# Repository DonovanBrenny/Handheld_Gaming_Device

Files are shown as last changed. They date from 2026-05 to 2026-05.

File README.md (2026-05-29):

# Handheld Gaming Device

A PIC24FJ64GA002 handheld game console with a 128x128 OLED, dual analog
joysticks, and four built-in games. Firmware in C, hardware in KiCad.

## Games

- **Pong** - two-player, first to 5
- **Ackanoid** - brick breaker, 3 levels, 3 lives
- **Maze** - 2.5D raycaster on a randomly generated maze
- **Dinosaur Runner** - endless side-scroller, jump with the blue button

## Controls

- **Joysticks** - menu navigation and in-game movement
- **Blue button** - select / jump
- **Red button** - back
- **Joystick click + Red (held)** - exit a game to the main menu

## Build

MPLAB X IDE + XC16 compiler. Open the `.X` folder as a project, build, and
flash with a PICkit (or equivalent) via the ICSP header.

## Hardware

KiCad schematic and PCB live in `hardware/`. Built around a PIC24FJ64GA002
(28-pin DIP), an SH1107-class 128x128 OLED on SPI1, two analog joysticks,
two pushbuttons, and an NPN-driven piezo speaker. Pin assignments are in
[`Setup.c`](Setup.c).

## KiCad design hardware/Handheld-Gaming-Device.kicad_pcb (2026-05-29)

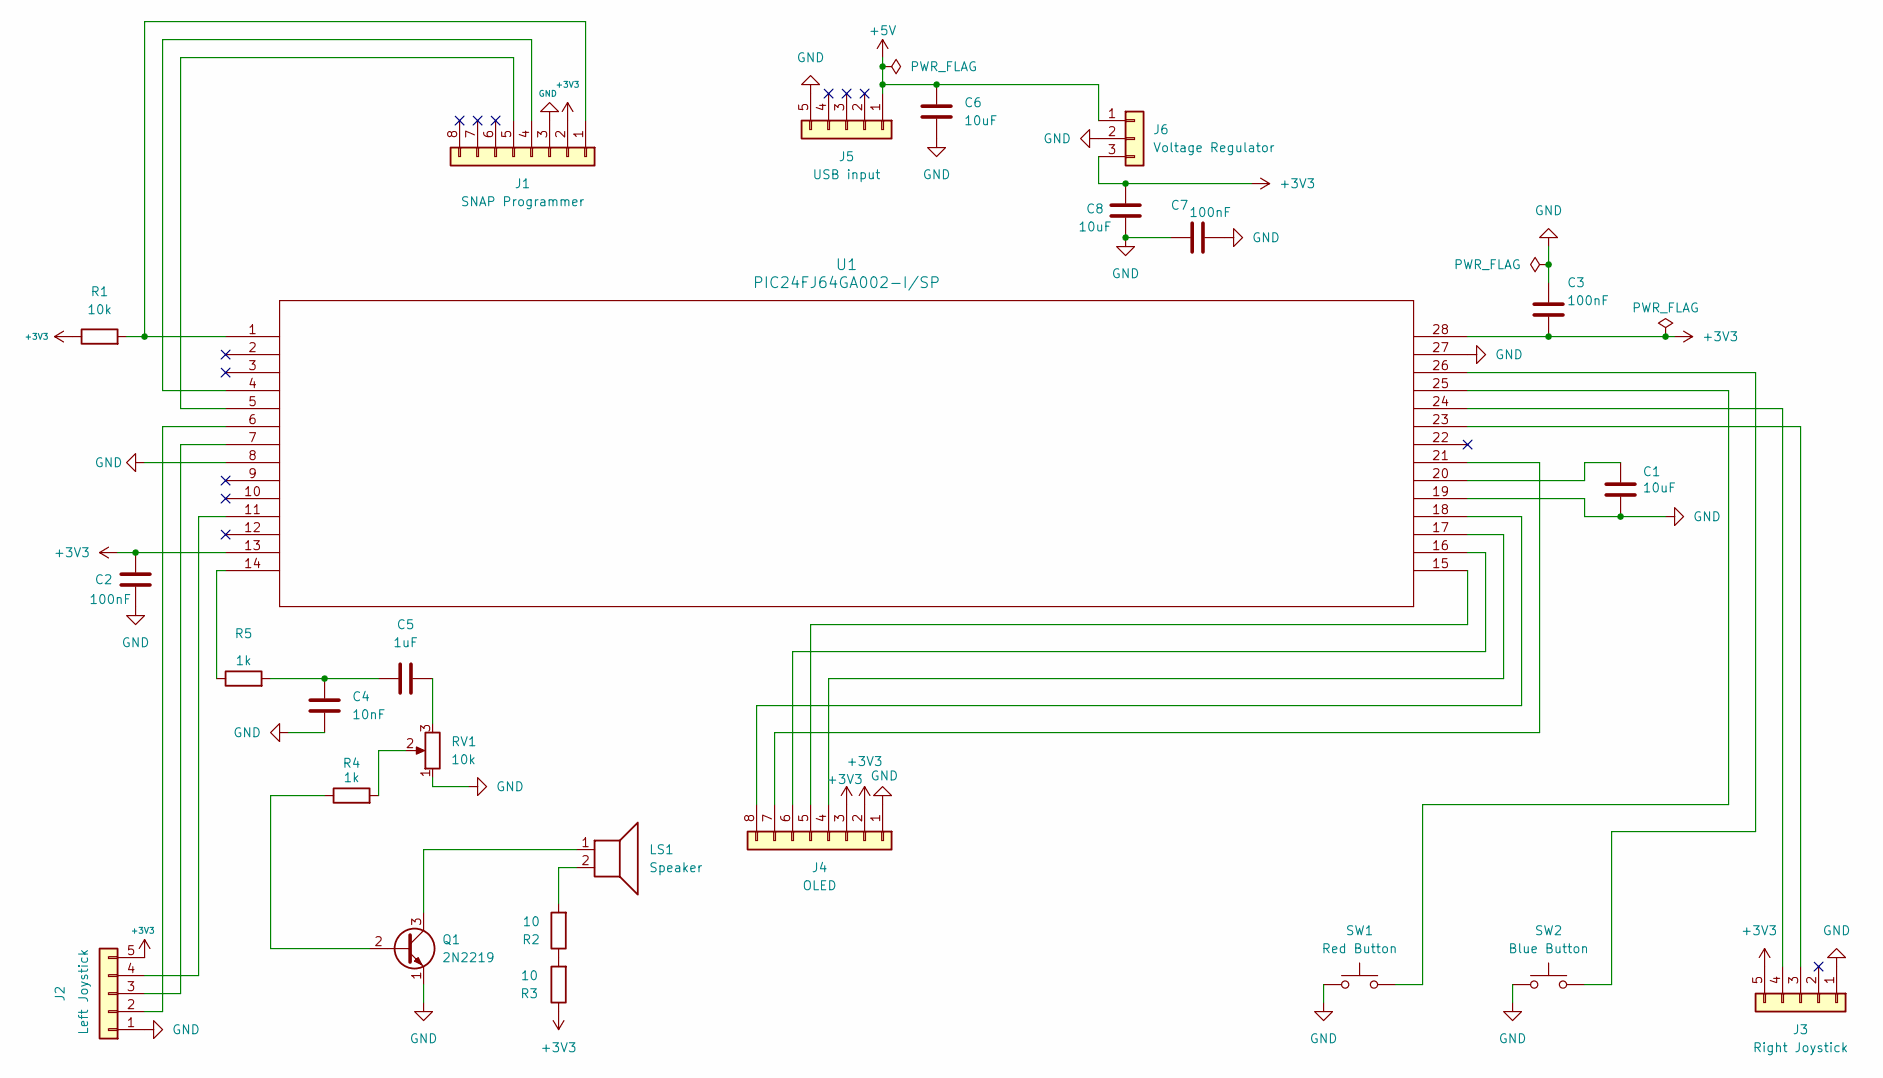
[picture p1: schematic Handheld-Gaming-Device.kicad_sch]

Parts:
C1, C6, C8: 10uF; C_Disc_D5.0mm_W2.5mm_P5.00mm
C2, C3, C7: 100nF; C_Disc_D5.0mm_W2.5mm_P5.00mm
C4: 10nF; C_Disc_D5.0mm_W2.5mm_P5.00mm
C5: 1uF; C_Disc_D5.0mm_W2.5mm_P5.00mm
J1: SNAP Programmer; PinSocket_1x08_P2.54mm_Vertical
J2: Left Joystick; PinSocket_1x05_P2.54mm_Vertical
J3: Right Joystick; PinSocket_1x05_P2.54mm_Vertical
J4: OLED; PinSocket_1x08_P2.54mm_Vertical
J5: USB input; PinSocket_1x05_P2.54mm_Vertical
J6: Voltage Regulator; TO-220-3_Vertical
LS1: Speaker; PinHeader_1x02_P2.54mm_Vertical
Q1: 2N2219; TO-39-3
R1: 10k; R_Axial_DIN0207_L6.3mm_D2.5mm_P10.16mm_Horizontal
R2, R3: 10; R_Axial_DIN0207_L6.3mm_D2.5mm_P10.16mm_Horizontal
R4, R5: 1k; R_Axial_DIN0207_L6.3mm_D2.5mm_P10.16mm_Horizontal
RV1: 10k; Potentiometer_Bourns_3386P_Vertical
SW1: Red Button; SW_PUSH_6mm
SW2: Blue Button; SW_PUSH_6mm
U1: PIC24FJ64GA002-I/SP; DIP-28_W7.62mm

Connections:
+3V3: C2.1, C3.2, C8.1, J1.2, J2.5, J3.5, J4.2, J4.3, J6.3, R1.1, R3.1, U1.13, U1.28
+5V: C6.1, J5.1, J6.1
GND: C1.2, C2.2, C3.1, C4.1, C6.2, C7.1, C7.2, C8.2, J1.3, J2.1, J3.1, J4.1, J5.5, J6.2, Q1.1 (E), RV1.1, SW1.1, SW2.1, U1.8, U1.19, U1.27
unnamed: C1.1, U1.20
unnamed: C4.2, C5.1, R5.2
unnamed: C5.2, RV1.3
unnamed: J1.1, R1.2, U1.1
unnamed: J1.4, U1.4
unnamed: J1.5, U1.5
unnamed: J2.2, U1.6
unnamed: J2.3, U1.7
unnamed: J2.4, U1.11
unnamed: J3.3, U1.23
unnamed: J3.4, U1.24
unnamed: J4.4, U1.17
unnamed: J4.5, U1.15
unnamed: J4.6, U1.16
unnamed: J4.7, U1.21
unnamed: J4.8, U1.18
unnamed: LS1.2, R2.2
unnamed: Q1.2 (B), R4.1
unnamed: LS1.1, Q1.3 (C)
unnamed: R2.1, R3.2
unnamed: R4.2, RV1.2
unnamed: R5.1, U1.14
unnamed: SW1.2, U1.25
unnamed: SW2.2, U1.26

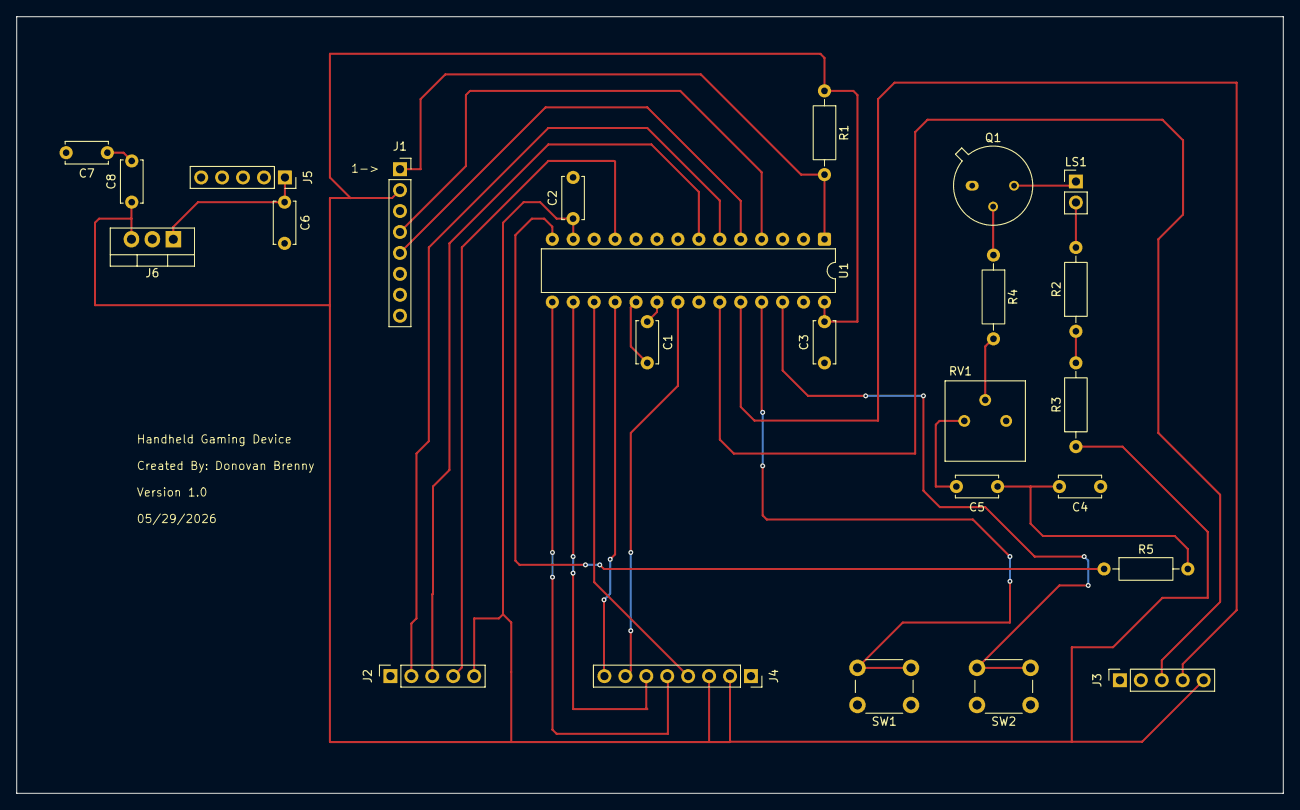
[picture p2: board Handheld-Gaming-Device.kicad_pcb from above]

Board: 2 copper layers, 153.7 x 94.2 mm, 25 parts (0 on the bottom side), 27 nets.

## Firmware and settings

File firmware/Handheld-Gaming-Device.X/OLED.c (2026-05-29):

/*
 * File:   OLED.c
 * Author: Donovan Brenny (brenn840)
 *
 * Created on November 15, 2025
 */

#include "xc.h"
#include <stdio.h>
#include <stdlib.h>
#include <stdint.h>
#include <string.h>
#include "game_ASM.h"
#include "6x8_font_table.h"
#include "OLED.h"
#include "OLED_drawings.h"


#define DATA_CMD_BIT LATBbits.LATB7
#define CHIP_SEL_BIT LATBbits.LATB8

#define BUFFER_SIZE (OLED_WIDTH * (OLED_HEIGHT / 8))

char OLED_BUFFER[BUFFER_SIZE];  // LOAD EACH OLED FRAME INTO HERE


void init_spi(void){
    
    IFS0bits.SPI1IF = 0;        // Clear the Interrupt flag
    IEC0bits.SPI1IE = 0;        // Disable the interrupt
    
    
    SPI1STATbits.SPIEN = 0;     //disable SPI1 to configure
    
    
    SPI1CON1bits.MSTEN = 1;     // Master mode
    SPI1CON1bits.MODE16 = 0;    // 8-bit for OLED commands
    SPI1CON1bits.CKP   = 0;     // Clock idle low
    SPI1CON1bits.CKE   = 1;     // Data changes on active-to-idle
    SPI1CON1bits.SMP   = 0;     // Sample in middle
    
    SPI1CON1bits.PPRE = 0b10;   // primary prescale 4:1
    SPI1CON1bits.SPRE = 0b111;  // secondary prescale 1:1
    
    
    SPI1STATbits.SPIROV = 0;     // Clear overflow
    //SPI1STATbits.SPISIDL = 0;  // Continue in idle
    
    SPI1STATbits.SPIEN = 1;      //Enable SPI1
}


unsigned char spi_write(char data_out){
    
    volatile unsigned char dummy;
    
    if (SPI1STATbits.SPIROV) {      // If an overflow ever happens clear it
        dummy = SPI1BUF;            // read to reset the buffer
        SPI1STATbits.SPIROV = 0;    // clear overflow flag
    }
    
    while(SPI1STATbits.SPITBF);     // Wait until TX buffer can accept data
    SPI1BUF = data_out;             // Write to TX buffer data
    
    while (!SPI1STATbits.SPIRBF);   // Wait for RX byte
    return (char)SPI1BUF;           // Return the data (It's Useless)
}


void oled_reset(void){
    
    LATBbits.LATB6 = 0;         // Pull RESET low
    st_1ms_delay();             // 1 millisecond delay
    LATBbits.LATB6 = 1;         // Pull RESET high
}

void oled_write_cmd(char cmd){
    
    CHIP_SEL_BIT = 0;           // CHIP SELECT LOW TO SELECT OLED
    DATA_CMD_BIT = 0;           // DATA/COMMAND LOW FOR COMMAND
    
    spi_write(cmd);             // SEND COMMAND
    
    CHIP_SEL_BIT = 1;           // CHIP SELECT HIGH TO DESELECT OLED
    
}

void oled_write_data(char data){
    
    CHIP_SEL_BIT = 0;           // CHIP SELECT BIT LOW TO SELECT OLED
    DATA_CMD_BIT = 1;           // DATA/COMMAND HIGH FOR DATA
    
    spi_write(data);            // SEND DATA
    
    CHIP_SEL_BIT = 1;           // CHIP SELECT HIGH TO DESELECT OLED
}

void oled_write_data_block(char *data, int len){
    
    CHIP_SEL_BIT = 0;           // CHIP SELECT BIT LOW TO SELECT OLED
    DATA_CMD_BIT = 1;           // DATA/COMMAND HIGH FOR DATA
    
    for(int i = 0; i < len; i++){
        spi_write(data[i]);
    }
    
    CHIP_SEL_BIT = 1;           // CHIP SELECT HIGH TO DESELECT OLED
}

void init_oled(void){
    
    oled_reset();               // Reset OLED
    
    oled_write_cmd(0xAE);       // Display OFF (sleep mode)
    
    // Display start line
    oled_write_cmd(0xDC);
    oled_write_cmd(0x00);       // start line = 0

    // Set contrast
    oled_write_cmd(0x81);
    oled_write_cmd(0x2F);       // medium contrast

    // Set memory addressing mode (horizontal)
    oled_write_cmd(0x20);
    oled_write_cmd(0x00);

    // Segment remap & COM scan direction (orientation)
    oled_write_cmd(0xA0);       // normal SEG mapping
    oled_write_cmd(0xC0);       // COM0 -> COM127

    // Multiplex ratio (height - 1)
    oled_write_cmd(0xA8);
    oled_write_cmd(0x7F);       // 0x7F = 127 => 128 rows

    // Display offset (vertical shift)
    oled_write_cmd(0xD3);
    oled_write_cmd(0x00);       // no offset for Adafruit 128x128 board

    // DC-DC control (internal booster on)
    oled_write_cmd(0xAD);
    oled_write_cmd(0x81);       // internal regulator on (datasheet power-on default)

    // Precharge & VCOMH (reasonable defaults)
    oled_write_cmd(0xD9);
    oled_write_cmd(0x22);

    oled_write_cmd(0xDB);
    oled_write_cmd(0x35);

    // Display follows RAM
    oled_write_cmd(0xA4);

    // Normal (non-inverted) display
    oled_write_cmd(0xA6);

    st_100ms_delay();           // let power settle

    oled_write_cmd(0xAF);       // display ON
    
    
    st_100ms_delay();           // Wait 100 milliseconds before sending data  
}


void clear_oled(void){

    memset(OLED_BUFFER,0x00,sizeof(OLED_BUFFER));   // Set each frame in the BUFFER to blank

}

void set_oled_contrast(unsigned char value){
    
    oled_write_cmd(0x81);
    oled_write_cmd((char)value);
}

void oled_set_pixel(int x, int y, int light){
    
    if (x >= OLED_WIDTH || y >= OLED_HEIGHT) return;    // OUT OF BOUNDS
    else if (x < 0 || y < 0) return;
    
    unsigned int index = x + (y/8) * OLED_WIDTH;    // Page indexing so divide y by 8
    
    int mask = 1 << (y & 7);              // 0 index the selected pixel
    
    if (light) {
        OLED_BUFFER[index] |= mask;     // Light = 1 to light pixel
    }
    else {
        OLED_BUFFER[index] &= ~mask;    // Light != 1 pixel stays dark
    }
}


void push_oled_frame(void){
    
    /*OLED STORES DATA IN PAGES(y) AND COLUMNS(x). 
     *USING PAGE INDEXING THERE IS 1 PIXEL/BIT PER PAGE AND 8 PER COLUMN
     *THE COLUMN BYTE SHOWS WHICH PIXELS ARE ON(1) or OFF(0)*/
    
    char pages = OLED_HEIGHT / 8;   // 8 pixels per page: 2048 pages
    
    for(int page = 0; page < pages; page++){
        
        oled_write_cmd(0xB0 | (page & 0x0F));       // Command to select a page

        
        unsigned int col = 0x00;        // Column counter

        oled_write_cmd(0x00 | (col & 0x0F));               // Set column low bits
        oled_write_cmd(0x10 | ((col >> 4) & 0x0F));        // Set column high bits

        
        char *pointer = &OLED_BUFFER[page *OLED_WIDTH];     // grabs memory data
        oled_write_data_block(pointer, OLED_WIDTH);         // writes a block of data
    }
}


void start_up_animation(void){

    const char *line1 = "GAME DEVICE";      // Title line at the top
    const char *line2 = "Donovan Brenny";   // Author line below the title

    int x1 = center_text_position(line1);   // Find center of line 1
    int x2 = center_text_position(line2);   // Find center of line 2

    int y_center = OLED_HEIGHT / 2;         // Center of Y-Axis

    int y1 = y_center - FONT_6x8_HEIGHT;    // Title sits just above the middle
    int y2 = y_center + (FONT_6x8_HEIGHT / 2);  // Author sits just below the middle

    draw_text(x1, y1, line1);               // Draw the title string on OLED
    draw_text(x2, y2, line2);               // Draw the author string on OLED

    push_oled_frame();                      // Push frames from OLED buffer

}
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

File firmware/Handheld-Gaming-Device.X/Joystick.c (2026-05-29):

/*
 * File:   Joystick.c
 * Author: Donovan Brenny
 *
 * Created on November 21, 2025
 */


#include "xc.h"
#include <stdint.h>
#include "game_ASM.h"
#include "Joystick.h"


#define JOY_CENTER 512
#define JOY_DEADZONE 12

// Initialize the read channel
static int read_joystick_channel(int channel);

// Raw axis levels
int x_axis_raw = 512;
int y_axis_raw = 512;

// Initial states of directions
int up = 0;
int down = 0;
int left = 0;
int right = 0;


// Initialize the joystick
void joystick_init(void){
    
    AD1CON1 = 0;
    AD1CON1bits.FORM = 0;
    AD1CON1bits.SSRC = 0b111;
    AD1CON1bits.ASAM = 0;
    
    // Sample time
    AD1CON3bits.SAMC = 16;    
    
    // Tad = (ADCS+1)*Tcy
    AD1CON3bits.ADCS = 2;     

    // Will set CH0SA in joystick_read_channel
    AD1CHS = 0;

    // Clear interrupt flag
    IFS0bits.AD1IF = 0;
    
    // We are polling, no interrupt
    IEC0bits.AD1IE = 0;

    // Turn on ADC
    AD1CON1bits.ADON = 1;
}


// Read the joystick
static int read_joystick_channel(int channel){
    
    // Select ANx
    AD1CHSbits.CH0SA = channel;

    AD1CON2 = 0;
    
    // Start sampling
    AD1CON1bits.SAMP = 1;
    
    // Small sample delay
    st_5us_delay();
    
    // Start conversion
    AD1CON1bits.SAMP = 0;

    // Wait for conversion
    while (!AD1CON1bits.DONE);   
    
    // Clear DONE
    AD1CON1bits.DONE = 0;

    return ADC1BUF0;
}


// Poll the joystick
void joystick_poll(int joystick){   // 0 for left, 1 for right
    
    // Variables for the change in the X / y directions of the joystick
    int x_change;
    int y_change;
    
    // Read the joystick data
    if (joystick){
        x_axis_raw = read_joystick_channel(JOY_X_CH_R);
        y_axis_raw = read_joystick_channel(JOY_Y_CH_R);
    }
    if (!joystick){
        x_axis_raw = read_joystick_channel(JOY_X_CH_L);
        y_axis_raw = read_joystick_channel(JOY_Y_CH_L);
    }
    
    // Change in the X / y directions of the joystick
    x_change = (x_axis_raw - JOY_CENTER);
    y_change = (y_axis_raw - JOY_CENTER);
    
    // SET / RESET the direction states
    up = 0;
    down = 0;
    left = 0;
    right = 0;
    
    /*IF X / Y CHANGE IS GREATER THAN DEADZONE SET NEW DIRECTION STATE */
    if(x_change > JOY_DEADZONE){
        right = 1;
        
    } else if (x_change < -JOY_DEADZONE) {
        left = 1;
    }

    if (y_change > JOY_DEADZONE) {
        down = 1;
        
    } else if (y_change < -JOY_DEADZONE) {
        up = 1;
    }
}

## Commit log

2026-05-29 Add README for handheld gaming device project
    Added detailed information about the handheld gaming device, including games, controls, build instructions, and hardware specifications.
2026-05-29 Uploaded all device files
    The whole handheld gaming device files
    [Handheld-Gaming-Device-B_Cu.gbr, Handheld-Gaming-Device-B_Mask.gbr, Handheld-Gaming-Device-B_Silkscreen.gbr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]
2026-05-29 PCB design change
    Changed the layout and size of the PCB
    [Handheld-Gaming-Device-B_Cu.gbr, Handheld-Gaming-Device-B_Mask.gbr, Handheld-Gaming-Device-B_Silkscreen.gbr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]
